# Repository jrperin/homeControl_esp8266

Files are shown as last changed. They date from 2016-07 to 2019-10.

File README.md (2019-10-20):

# Gravando programas no ESP8266

## Preparando o ambiente

#### Instalar arduino IDE 1.6.8 do site do arduino:

[https://www.arduino.cc/en/Main/Software](https://www.arduino.cc/en/Main/Software)

#### Adicione uma nova origem no gerenciados de placas da IDE do arduino.

1. Menu: Arquivo > Preferências > Configurações
 * No campo URLs adicionais de gerenciadores de placas adicione:
    * http://arduino.esp8266.com/stable/package_esp8266com_index.json
    * Múltiplas URLs podem ser adicionadas separando-as por vígulas.

2. Menu: Ferramentas > Placa > Gerenciador de Placas
 * No campo de busca coloque esp8266 e instale o gerenciador referente à placa (_esp8266 by ESP8266 Community_)
 
#### Instalar Dependencias  

1. ESP8266WiFi  
 ```
   cd ~/arduino  
   cd hardware  
   mkdir esp8266com  
   cd esp8266com  
   git clone https://github.com/esp8266/Arduino.git esp8266  
   cd esp8266/tools  
   python get.py  
 ```
 * Reiniciar a IDE do Arduino  
   
2. pubsub 
  * Sketch -> Incluir Bibliotecas -> Gerenciar Bibliotecas... -> Digitar PubSub no campo de busca -> Install (PubSubClient by Nick O'Leary)
    
3. RemoteDebug
  * Sketch -> Incluir Bibliotecas -> Gerenciar Bibliotecas... -> Digitar remotedebug no campo de busca -> instalar (Joao Lopes / RemoteDebug)

#### Habilitar porta serial no Linux

  1. Abra o terminal e inclua o usuário nos grupos "tty" e "dialout", com os comandos:
```
  $ sudo usermod -a -G tty teu_usuario
  $ sudo usermod -a -G dialout teu_usuario
```
  2. Agora faça logout e em seguida, login novamente.

  3. Para verificar se os grupos foram incluídos, use o comando:
```
  $ groups
```

#### PL230HX

PL2303HX - USB Conector

[Download Windows Driver](http://www.prolific.com.tw/US/ShowProduct.aspx?p_id=225&pcid=41)

__Problemas em reconhecer o módulo no desktop novo:__  
  
Na Bios alterar:  
> - USB legacy mode off  
> - XHCI hands-off - enable  

Alterar o arquivo:  
> * /etc/default/grub  
> Adicionar alinha:  
> GRUB_CMDLINE_LINUX="iommu=soft"  
  
Salvar e recriar o grup com:  
> * sudo update-grub.  

## CH340G - Protótipo
http://fobit.blogspot.com/2014/11/ch340g-in-eagle.html

## Preparando o Hardware

Gravar o programa no ESP8266

O programa de exemplo do próprio arduino ocasionava o erro abaixo:

 ets Jan  8 2013,rst cause:4, boot mode:(3,3)

wdt reset
load 0x4010f000, len 1384, room 16 
tail 8
chksum 0x2d
csum 0x2d
v09f0c112
~ld

Usando outros programas funcionou normalmente.

## Extras

1. Site do fabricante:

 > http://bbs.espressif.com/index.php

2. Imagem SDK para atualização (_versão atual no momento_):
 
 > http://bbs.espressif.com/download/file.php?id=1469

3. Guia Linux de como atualizar o firmware do ESP8266 pelo NodeMCU:
 
 > Link do guia: http://www.whatimade.today/flashing-the-nodemcu-firmware-on-the-esp8266-linux-guide/

 > Baixar o esptool: https://github.com/themadinventor/esptool
 
 > **Command de atualização do firmware no esp8266:**
 
 > ./esptool.py -p /dev/ttyUSB0 write_flash 0x000000 v0.9.5.2\ AT\ Firmware.bin

4. Links interessantes:
  
  > http://www.whatimade.today/esp8266-easiest-way-to-program-so-far/

  > http://blog.thethings.io/connect-esp8266-to-the-internet-at-thethings-io/
  
  > iot eclipse mosquito (mqtt broker)
  > * http://mosquitto.org/download/
  > * http://www.switchdoc.com/2016/02/tutorial-installing-and-testing-mosquitto-mqtt-on-raspberry-pi/

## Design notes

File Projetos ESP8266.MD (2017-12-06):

#Projetos utilizando ESP8266

##### esp8266 com websockets mdns ota e leds

  > http://www.whatimade.today/esp8266-on-websockets-mdns-ota-and-leds/

##### Programação do ESP8266 via OTA com wifi
  > https://www.filipeflop.com/blog/programacao-esp8266-ota-wifi/

##### Servo Articulation of Web Cam with ESP8266 01 and Blynk  
  > http://www.whatimade.today/servo-articulation-of-web-cam-with-esp8266-01-and-blynk/

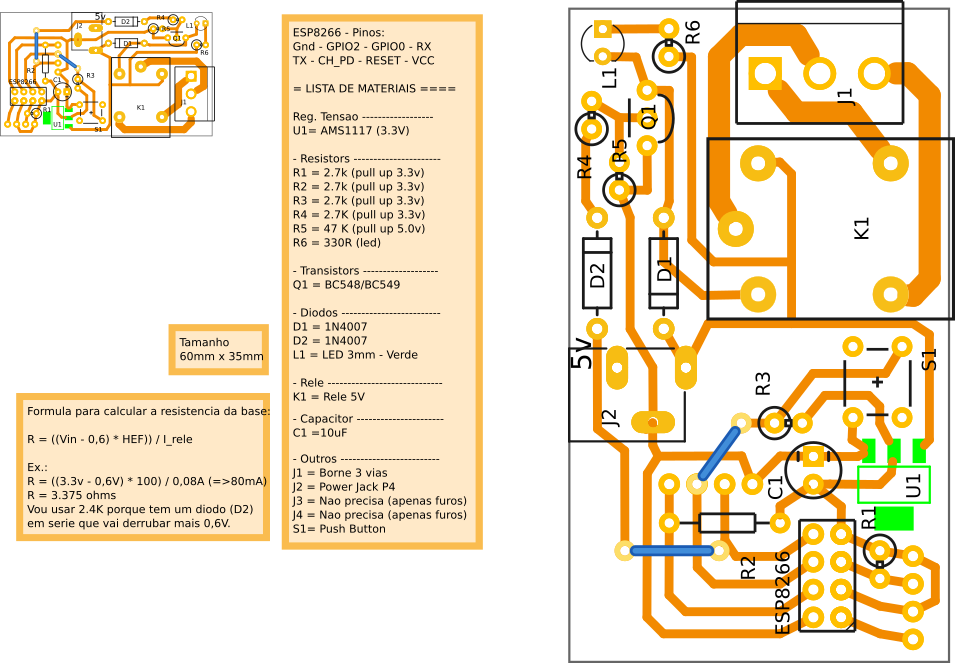
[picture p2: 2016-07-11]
fritzing/relayControl_esp8266/esp8266_rele_v5.1_pcb.png

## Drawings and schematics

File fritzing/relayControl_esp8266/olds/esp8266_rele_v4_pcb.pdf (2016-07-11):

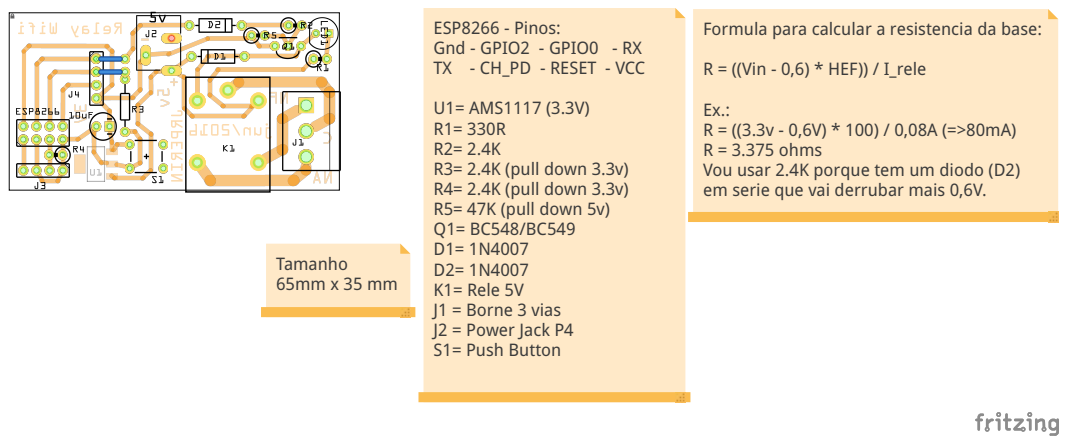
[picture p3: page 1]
R = ((Vin - 0,6) * HEF)) / I_rele; Tamanho 65mm x 35 mm; U1= AMS1117 (3.3V) R1= 330R R2= 2.4K R3= 2.4K (pull down 3.3v) R4= 2.4K (pull down 3.3v) R5= 47K (pull down 5v) Q1= BC548/BC549 D1= 1N4007 D2= 1N4007 K1= Rele 5V J1 = Borne 3 vias J2 = Power Jack P4 S1= Push Button

ESP8266 - Pinos:
Gnd - GPIO2 - GPIO0 - RX
TX - CH_PD - RESET - VCC

Formula para calcular a resistencia da base:

R = 3.375 ohms
Vou usar 2.4K porque tem um diodo (D2)
em serie que vai derrubar mais 0,6V.

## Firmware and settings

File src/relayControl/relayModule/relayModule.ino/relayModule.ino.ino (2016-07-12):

#include "ESP8266WiFi.h"
#include <ESP8266mDNS.h>
#include <WiFiClient.h>
#include <EEPROM.h>
#include <cstring>

MDNSResponder mdns;
WiFiServer server(80);

char* ssid = "relayModule";
String st;
byte relayStatus = 0;
byte ambiente = 1;

uint8_t MAC_array[6];
//char MAC_char[18];
//char MAC_char_ssid[12];
String mac_addr = "";
String mac_addr_clear = "";

 

/* GPIO0 = 0 ; GPIOTXD = 1 ; GPIO2 = 2 ; GPIORXD = 3 */
#define relayTest 2  //Test
#define relayProd 3  //Production
#define apMode    0  // GPIO0 coloca em modo AP


void setup() {
  Serial.begin(115200);
  EEPROM.begin(512);
  delay(10);
  Serial.println();
  Serial.println();
  Serial.println("Startup");

  pinMode(relayTest, OUTPUT);
  digitalWrite(relayTest, LOW);
  pinMode(relayProd, OUTPUT);
  digitalWrite(relayProd, LOW);

  WiFi.macAddress(MAC_array);

    Serial.println("MAC_array");
    for (int i = 0; i < sizeof(MAC_array); i++){
      Serial.print(MAC_array[i]);
      Serial.print(" => ");
      Serial.println(String(MAC_array[i], HEX));
    }
    Serial.println("MAC_array - fim");
    
    for (int i = 0; i < sizeof(MAC_array); i++){
      String strAux = "0" + String(MAC_array[i], HEX);
      strAux = strAux.substring(strAux.length() -2, strAux.length());
      mac_addr +=  strAux;
      mac_addr_clear += strAux;
      if (i < sizeof(MAC_array)-1){
           mac_addr += ":";
      }
    }

    String ssidFullName = "relayControl_" + mac_addr_clear;
    strcpy(ssid, ssidFullName.c_str());

    Serial.print("mac_addr: [");
    Serial.print(mac_addr);
    Serial.println("]");

    Serial.print("mac_addr_clear: [");
    Serial.print(mac_addr_clear);
    Serial.println("]");

    Serial.print("ssid: [");
    Serial.print(ssid);
    Serial.println("]");
    
  
  setupAP(); 
}

/*
 * Converting from Hex to Decimal:
 * NOTE: This function can handle a positive hex value from 0 - 65,535 (a four digit hex string).
 *       For larger/longer values, change "unsigned int" to "long" in both places.
 */
unsigned int hexToDec(String hexString) {
  
  unsigned int decValue = 0;
  int nextInt;
  
  for (int i = 0; i < hexString.length(); i++) {
    
    nextInt = int(hexString.charAt(i));
    if (nextInt >= 48 && nextInt <= 57) nextInt = map(nextInt, 48, 57, 0, 9);
    if (nextInt >= 65 && nextInt <= 70) nextInt = map(nextInt, 65, 70, 10, 15);
    if (nextInt >= 97 && nextInt <= 102) nextInt = map(nextInt, 97, 102, 10, 15);
    nextInt = constrain(nextInt, 0, 15);
    
    decValue = (decValue * 16) + nextInt;
  }
  
  return decValue;
}



void launchWeb(int webtype) {
          Serial.println("");
          Serial.println("WiFi connected");
          Serial.println(WiFi.localIP());
          Serial.println(WiFi.softAPIP());
          
          // Start the server
          server.begin();
          Serial.println("Server started");   
          int b = 20;
          int c = 0;
          while(b == 20) { 
             b = mdns1(webtype);
           }
}




void setupAP(void) {
  
  WiFi.mode(WIFI_STA);
  WiFi.disconnect();
  delay(100);

  WiFi.softAP(ssid);
  Serial.println("softap");
  Serial.println("");
  launchWeb(1);
  Serial.println("over");
  
}


String getHtml(void){
  
  String s;
  String btStatus;
  String btSubmit;
  String btAmbiente;
  
  IPAddress ip = WiFi.softAPIP();
  String ipStr = String(ip[0]) + '.' + String(ip[1]) + '.' + String(ip[2]) + '.' + String(ip[3]);
  
  if (relayStatus == 0){
    btStatus    = "<input type='submit' style='color: gray; font-weight: 900; width: 160px; height: 80px; font-size: 2em' value='OFF'>";
    btSubmit    = "<input name='status' length=1 value='1' style='display: none'>";
  } else {
    btStatus    = "<input type='submit' style='color: limegreen; font-weight: 900; width: 160px; height: 80px; font-size: 2em' value='ON'>";
    btSubmit    = "<input name='status' length=1 value='0' style='display: none'>";
  }

  if (ambiente){
    btAmbiente  = "<input type='radio' name='ambiente' value='0'> teste <br>";
    btAmbiente += "<input type='radio' name='ambiente' value='1' checked='checked'> produção <br>";
  } else {
    btAmbiente  = "<input type='radio' name='ambiente' value='0' checked='checked'> teste <br>";
    btAmbiente += "<input type='radio' name='ambiente' value='1' > produção <br>";
  }

  s  = "HTTP/1.1 200 OK\r\nContent-Type: text/html \r\n\r\n";
  s += "<!DOCTYPE HTML> \r\n";
  s += "<html>";
  s += "<head>";
  s += "<meta charset='UTF-8'>";
  s += "<meta name='viewport' content='initial-scale=1, maximum-scale=1, user-scalable=no, width=device-width'>";
  s += "<style>"; 
  s += "body {font-family: Arial, Helvetica, sans-serif; font-size:large; text-align: center}";
  s += "</style>";
  s += "</head>";
  s += "<body>";
  s += "<h1> relayControl_ </h1>";
  s += "<h3>" + ipStr + "</h3>";
  s += "<h4>" + mac_addr + "</h4>";
  s += "<br>";
  s += "<form method='get' action='a'>";
  s += "<div style='width: 180px; margin:auto; text-align: left'>";
  s += btAmbiente;
  s += "</div>";
  s += "<br>";
  s += btStatus;
  s += btSubmit;
  s += "</form>";
  s += "</body>";
  s += "</html> \r\n\r\n";

  return s;

}


int mdns1(int webtype)
{
  // Check for any mDNS queries and send responses
  
  // Check if a client has connected
  WiFiClient client = server.available();
  if (!client) {
    return(20);
  }
  
  Serial.println("");
  Serial.println("New client");

  // Wait for data from client to become available
  while(client.connected() && !client.available()){
    delay(1);
   }
  
  // Read the first line of HTTP request
  String req = client.readStringUntil('\r');
  

  // First line of HTTP request looks like "GET /path HTTP/1.1"
  // Retrieve the "/path" part by finding the spaces
  int addr_start = req.indexOf(' ');
  int addr_end = req.indexOf(' ', addr_start + 1);
  if (addr_start == -1 || addr_end == -1) {
    Serial.print("Invalid request: ");
    Serial.println(req);
    return(20);
   }
   
  req = req.substring(addr_start + 1, addr_end);
  Serial.print("Request: [");
  Serial.print(req);
  Serial.println("]");
  client.flush(); 
  
  String s ;
  
  
  if (req == "/") {
    Serial.println("entrou em '/'");    
    Serial.println("Sending 200");
    s = getHtml();
    
  } else if ( req.startsWith("/a?ambiente=") ) {
    Serial.println("entrou em /a?status=");
    // /a?ambiente=0&status=1

    ambiente    = req.substring(12,req.indexOf('&')).toInt();
    relayStatus = req.substring(req.lastIndexOf('=')+1).toInt();

    int relay = relayProd;
    if (!ambiente){
      relay = relayTest;
    }
    
    if (relayStatus){
      digitalWrite(relay, HIGH);
    } else {
      digitalWrite(relay, LOW);
    }
    
    Serial.print("relayStatus = ");
    Serial.println(relayStatus);
    Serial.println();
    s = getHtml();

  } else {
    Serial.println("Entrou no ELSE");
    s = "HTTP/1.1 404 Not Found\r\n\r\n";
    Serial.println("Sending 404");
  }

  Serial.println(s);
  Serial.println();
  client.print(s);
  
  Serial.println("Done with client");
  return(20);
}



void loop() {
  // put your main code here, to run repeatedly:

}

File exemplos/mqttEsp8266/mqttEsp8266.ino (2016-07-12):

/*
 Basic ESP8266 MQTT example
 This sketch demonstrates the capabilities of the pubsub library in combination
 with the ESP8266 board/library.

 It connects to an MQTT server then:
  - publishes "hello world" to the topic "outTopic" every two seconds
  - subscribes to the topic "inTopic", printing out any messages
    it receives. NB - it assumes the received payloads are strings not binary
  - If the first character of the topic "inTopic" is an 1, switch ON the ESP Led,
    else switch it off

 It will reconnect to the server if the connection is lost using a blocking
 reconnect function. See the 'mqtt_reconnect_nonblocking' example for how to
 achieve the same result without blocking the main loop.

 To install the ESP8266 board, (using Arduino 1.6.4+):
  - Add the following 3rd party board manager under "File -> Preferences -> Additional Boards Manager URLs":
       http://arduino.esp8266.com/stable/package_esp8266com_index.json
  - Open the "Tools -> Board -> Board Manager" and click install for the ESP8266"
  - Select your ESP8266 in "Tools -> Board"

*/

#include <ESP8266WiFi.h>
#include <PubSubClient.h>

#define BUILTIN_LED 2

// Update these with values suitable for your network.
const char* ssid = "Thor";
const char* password = "pitoco@perin1975";
//const char* mqtt_server = "broker.mqtt-dashboard.com";
const char* mqtt_server = "easyiso.io";

WiFiClient espClient;
PubSubClient client(espClient);
long lastMsg = 0;
char msg[50];
int value = 0;


void setup() {
  pinMode(BUILTIN_LED, OUTPUT);     // Initialize the BUILTIN_LED pin as an output
  Serial.begin(115200);
  setup_wifi();
  client.setServer(mqtt_server, 1883);
  client.setCallback(callback);
}

void setup_wifi() {

  delay(10);
  // We start by connecting to a WiFi network
  Serial.println();
  Serial.print("Connecting to ");
  Serial.println(ssid);

  WiFi.begin(ssid, password);

  while (WiFi.status() != WL_CONNECTED) {
    delay(500);
    Serial.print(".");
  }

  Serial.println("");
  Serial.println("WiFi connected");
  Serial.println("IP address: ");
  Serial.println(WiFi.localIP());
}

void callback(char* topic, byte* payload, unsigned int length) {
  Serial.print("Message arrived [");
  Serial.print(topic);
  Serial.print("] ");
  for (int i = 0; i < length; i++) {
    Serial.print((char)payload[i]);
  }
  Serial.println();

  // Switch on the LED if an 1 was received as first character
  if ((char)payload[0] == '1') {
    digitalWrite(BUILTIN_LED, LOW);   // Turn the LED on (Note that LOW is the voltage level
    // but actually the LED is on; this is because
    // it is acive low on the ESP-01)
  } else {
    digitalWrite(BUILTIN_LED, HIGH);  // Turn the LED off by making the voltage HIGH
  }

}

void reconnect() {
  // Loop until we're reconnected
  while (!client.connected()) {
    Serial.print("Attempting MQTT connection...");
    // Attempt to connect
    if (client.connect("ESP8266Client")) {
      Serial.println("connected");
      // Once connected, publish an announcement...
      client.publish("outTopic", "hello world");
      // ... and resubscribe
      client.subscribe("inTopic");
    } else {
      Serial.print("failed, rc=");
      Serial.print(client.state());
      Serial.println(" try again in 5 seconds");
      // Wait 5 seconds before retrying
      delay(5000);
    }
  }
}
void loop() {

  if (!client.connected()) {
    reconnect();
  }
  client.loop();

  long now = millis();
  if (now - lastMsg > 2000) {
    lastMsg = now;
    ++value;
    snprintf (msg, 75, "hello world #%ld", value);
    Serial.print("Publish message: ");
    Serial.println(msg);
    client.publish("outTopic", msg);
  }
}

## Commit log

2016-07-05 Atualizandotodos os .ino - wifi-boot esta pronto para usar no esp8266
2016-07-07 Criado o diretorio exemplos Diretorio ./src sera utilizado para os fontes que serao upados para o esp8266
2016-07-07 removido a pasta arduino da arvore do caminho. diretorio sera: /src/relayControl
2016-07-07 Atualizado HTML para acender apagar lampada (relay)
2016-07-11 Adicionando fritzing ao projeto
    [esp8266_rele.fzz, esp8266_rele_v2.fzz, esp8266_rele_v3.fzz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]
2017-12-08 PL2303HX - USB Dongle Driver
    PL2303HX - USB Dongle Driver
2017-12-08 Download Driver USB - PL230HX
    Download Driver USB - PL230HX
2017-12-08 Alterando imagem de lugar, incluindo driver PL230HX_USB_WIN10
